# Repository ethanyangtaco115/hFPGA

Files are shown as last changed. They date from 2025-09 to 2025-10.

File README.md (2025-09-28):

# hFPGA (WIP)

A modified PicoEVB FPGA board made for rapid prototyping, DIY projects, and making FPGAs more accessible to hobbyists
Sub-System of our Flash LiDAR Project

## Acknowledgements

 - [Major Credit to PicoEVB creators, who made the base schematic for our design.](https://github.com/RHSResearchLLC/PicoEVB/tree/master)

## Features

- 78 Total I/O Pins
- SPI Flash Boot capability
- Integrated USB-JTAG support
- 4 ADC Pins
- 4 Clock Output Pins
- 4 3.3v PWR Pins
- 6 True Single-Ended GPIO Pins
- 15 Differential Lines, with Pseudo-Single Ended capability
- 24 GND Pins

# Authors

Created by [Ethan Yang](https://github.com/ethanyangtaco115) & [Stanley Wang](https://github.com/GhostWinterOwl)

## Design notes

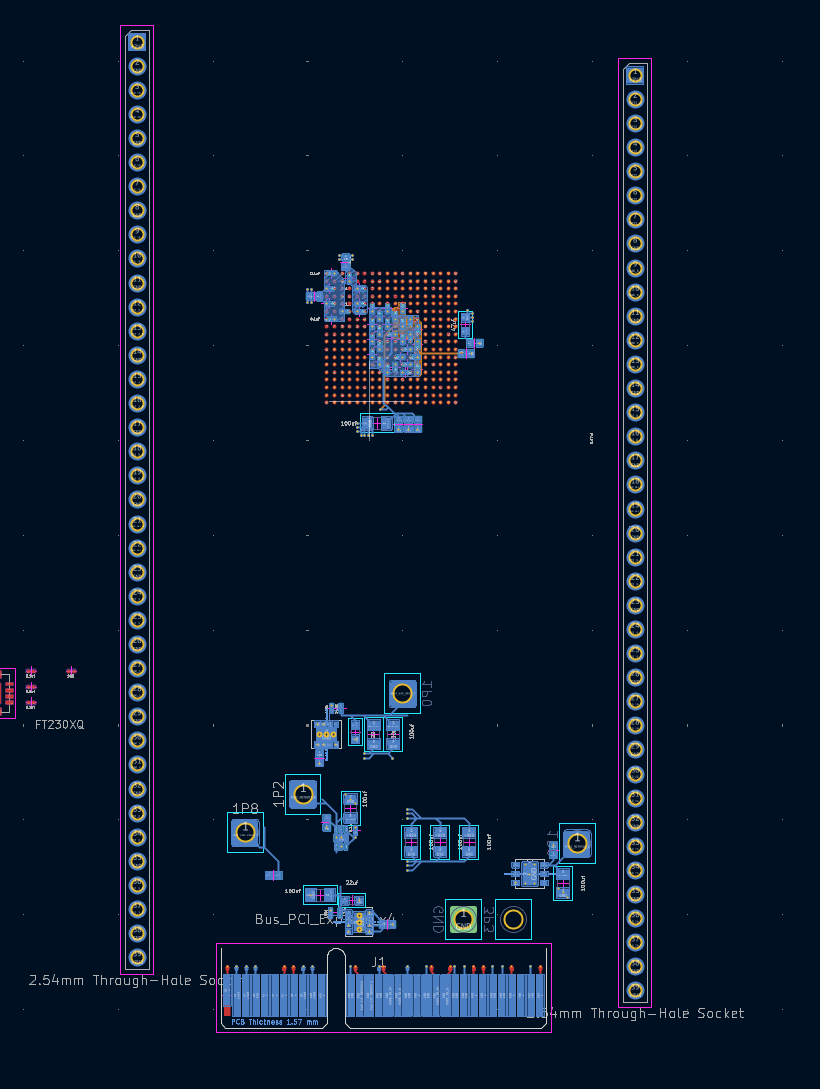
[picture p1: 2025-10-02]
images/image.png

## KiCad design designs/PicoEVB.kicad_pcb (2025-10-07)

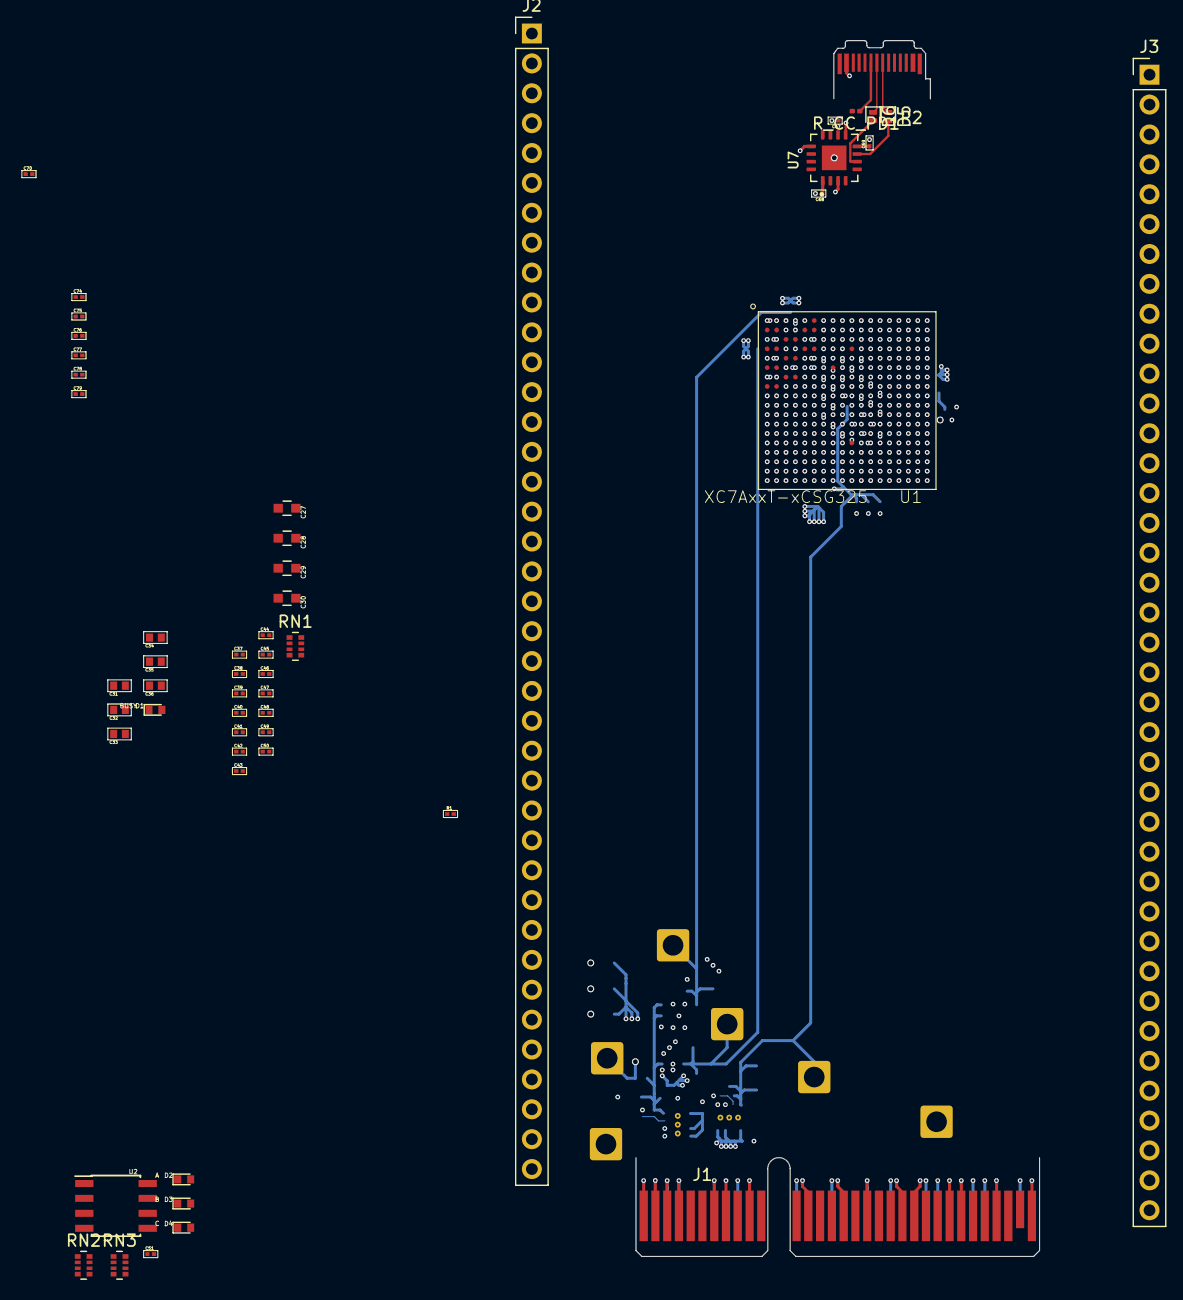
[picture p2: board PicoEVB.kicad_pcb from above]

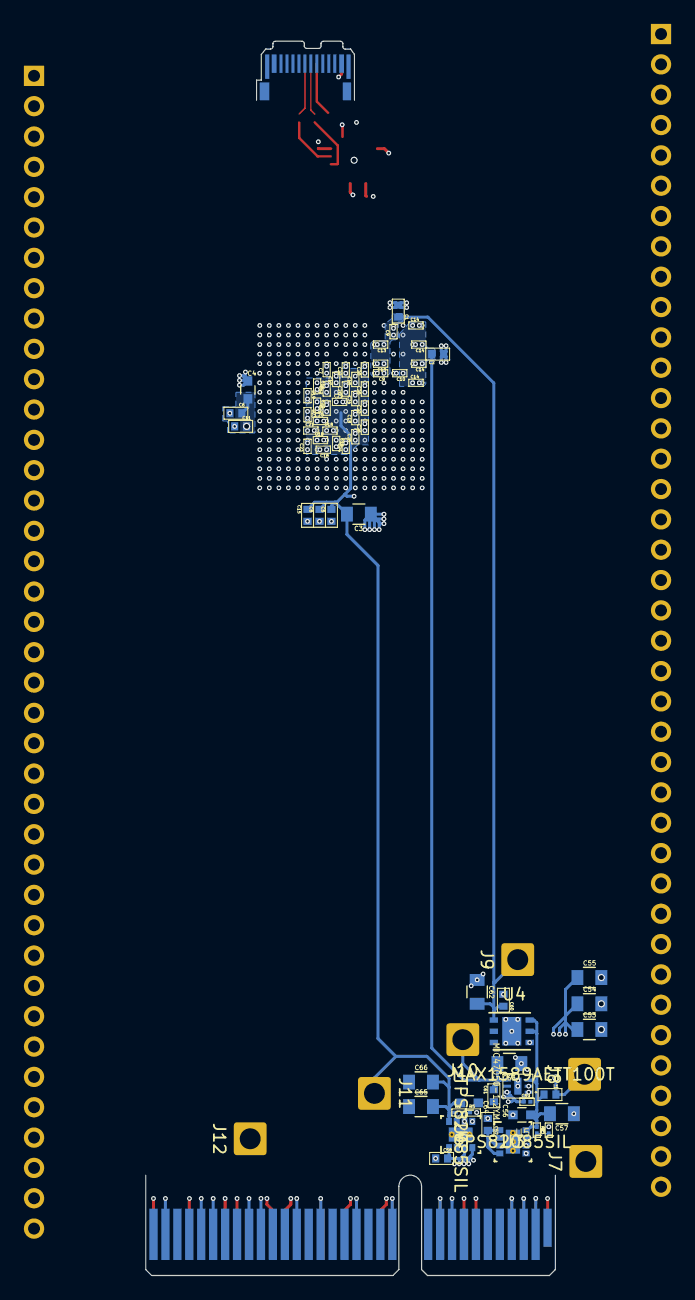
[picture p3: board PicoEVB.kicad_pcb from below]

Board: 6 copper layers, 128 parts (75 on the bottom side), 104 nets.

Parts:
C1, C2, C5, C6, C8, C11, C15, C31, C32, C33, C34, C35, C36: 4.7uf; c_0402
C3, C53, C54, C55, C57, C62, C63, C65, C66: 100uf; C_0805
C4, C27, C28, C29, C30: 47uf; C_0603
C7, C12, C16, C17, C18, C18#2, C18#3, C18#4, C18#5, C18#6, C19, C20, C20#2, C20#3, C21, C21#2, C22, C22#2, C22#3, C23, C23#2, C24, C24#2, C25, C25#2, C26, C26#2, C37, C38, C39, C40, C41, C42, C43, C44, C45, C46, C47, C48, C49, C50, C70: 0.47uf; c_0201_least
C9, C9#2, C10, C13, C13#2, C14, C14#2, C14#3, C14#4, C51, C59, C67, C68, C69, C74, C75, C76, C77, C78, C79: 0.1uf; c_0201_least
C52, C58, C60, C61: 10uf; c_0402
C56, C64: 22uf; C_0603
D1: BUSY; LED_0402
D2: A; LED_0402
D3: B; LED_0402
D4: C; LED_0402
D5, D6: PESD5V0S1UL; D_SOD-882
J1: Bus_PCI_Express_x4; BUS_PCIexpress_x4
J2, J3: 2.54mm Through-Hole Socket; PinHeader_1x39_P2.54mm_Vertical
J7: 3P3; SolderWire-1sqmm_1x01_D1.4mm_OD2.7mm
J8: 1P8; SolderWire-1sqmm_1x01_D1.4mm_OD2.7mm
J9, J11: 1P0; SolderWire-1sqmm_1x01_D1.4mm_OD2.7mm
J10: 1P2; SolderWire-1sqmm_1x01_D1.4mm_OD2.7mm
J12: GND; SolderWire-1sqmm_1x01_D1.4mm_OD2.7mm
L1: 330; r_0402
P2: USB_C_Plug_USB2.0; USB_C_Plug_JAE_DX07P024AJ1
R1: 100; r_0201_least
R2: 124k; r_0201_least
R3, R5: 100k; r_0201_least
R4: 24.9k; r_0201_least
RN1, RN3: 4.7K; R_Array_Convex_4x0402
RN2: 681; R_Array_Convex_4x0402
R_CC_PD1: 5.1k; R_0201_0603Metric
U1: XC7AxxT-xCSG325; CSG-324
U2: S25Q; SOIC-8_3.9x4.9mm_Pitch1.27mm
U3, U6: TPS82085SIL; TPS82084SILR
U4: MAX1589AETT100T
U5: MIC47050-1.2YML; MIC47050-DFN-6-2MM
U7: FT230XQ; QFN65P400X400X80-17N

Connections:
+3V3: C52.1, C53.1, C54.1, C55.1, C58.1, C59.1, C67.1, C68.1, C69.1, C70.2, J1.A2 (+12V), J1.A3 (+12V), J1.A9 (+3.3V), J1.A10 (+3.3V), J1.B1 (+12V), J1.B2 (+12V), J1.B3 (+12V), J1.B8 (+3.3V), J1.B10 (3.3Vaux), J2.1, J2.39, J3.1, J3.39, U3.1 (EN), U3.3 (VIN), U3.4 (VIN), U5.1 (BIAS), U5.6 (EN), U6.1 (EN), U6.3 (VIN), U6.4 (VIN), U7.1 (VCCIO), U7.8 (3V3OUT), U7.10 (VCC)
BUSY_LED_PU: D1.2 (A), RN2.5 (R4.2)
DIO_1_N: J2.36, U1.B17 (IO_L16N_T2_A27_15)
DIO_1_P: J2.37, U1.C16 (IO_L16P_T2_A28_15)
DIO_2_N: J2.33, U1.D18 (IO_L17N_T2_A25_15)
DIO_2_P: J2.34, U1.E17 (IO_L17P_T2_A26_15)
DIO_3_N: J2.24, U1.C18 (IO_L18N_T2_A23_15)
DIO_3_P: J2.25, U1.C17 (IO_L18P_T2_A24_15)
DIO_4_N: J3.16, U1.G16 (IO_L20N_T3_A19_15)
DIO_4_P: J3.15, U1.H16 (IO_L20P_T3_A20_15)
DIO_5_N: J2.18, U1.F14 (IO_L22N_T3_A16_15)
DIO_5_P: J2.19, U1.G14 (IO_L22P_T3_A17_15)
DIO_6_N: J3.22, U1.H18 (IO_L23N_T3_FWE_B_15)
DIO_6_P: J3.21, U1.H17 (IO_L23P_T3_FOE_B_15)
DIO_7_N: J2.15, U1.E18 (IO_L24N_T3_RS0_15)
DIO_7_P: J2.16, U1.F17 (IO_L24P_T3_RS1_15)
DIO_8_N: J3.25, U1.K5 (IO_L1N_T0_34)
DIO_8_P: J3.24, U1.K6 (IO_L1P_T0_34)
DIO_9_N: J2.12, U1.J4 (IO_L2N_T0_34)
DIO_9_P: J2.13, U1.J5 (IO_L2P_T0_34)
DIO_10_N: J3.28, U1.L2 (IO_L4N_T0_34)
DIO_10_P: J3.27, U1.K3 (IO_L4P_T0_34)
DIO_11_N: J2.9, U1.L3 (IO_L5N_T0_34)
DIO_11_P: J2.10, U1.L4 (IO_L5P_T0_34)
DIO_12_N: J3.31, U1.M1 (IO_L7N_T1_34)
DIO_12_P: J3.30, U1.M2 (IO_L7P_T1_34)
DIO_13_N: J2.6, U1.N6 (IO_L8N_T1_34)
DIO_13_P: J2.7, U1.M6 (IO_L8P_T1_34)
DIO_14_N: J3.34, U1.N4 (IO_L10N_T1_34)
DIO_14_P: J3.33, U1.M4 (IO_L10P_T1_34)
DIO_15_N: J2.3, U1.T3 (IO_L17N_T2_34)
DIO_15_P: J2.4, U1.T4 (IO_L17P_T2_34)
DIO_16_N: J3.37, U1.V4 (IO_L18N_T2_34)
DIO_16_P: J3.36, U1.U4 (IO_L18P_T2_34)
FPGA_CCLK_0_B: U1.E8 (CCLK_0), U2.6 (SCK)
GND: C1.2, C2.2, C3.2, C4.2, C5.2, C6.2, C7.2, C8.2, C9.2, C9#2.2, C10.2, C11.2, C12.2, C13.2, C13#2.2, C14.2, C14#2.2, C14#3.2, C14#4.2, C15.2, C16.2, C17.2, C18.2, C18#2.2, C18#3.2, C18#4.2, C18#5.2, C18#6.2, C19.2, C20.2, C20#2.2, C20#3.2, C21.2, C21#2.2, C22.2, C22#2.2, C22#3.2, C23.2, C23#2.2, C24.2, C24#2.2, C25.2, C25#2.2, C26.2, C26#2.2, C27.2, C28.2, C29.2, C30.2, C31.2, C32.2, C33.2, C34.2, C35.2, C36.2, C37.2, C38.2, C39.2, C40.2, C41.2, C42.2, C43.2, C44.2, C45.2, C46.2, C47.2, C48.2, C49.2, C50.2, C51.2, C52.2, C53.2, C54.2, C55.2, C56.2, C57.2, C58.2, C59.2, C60.2, C61.2, C62.2, C63.2, C64.2, C65.2, C66.2, C67.2, C68.2, C69.2, C70.1, J1.A4 (GND), J1.A12 (GND), J1.A15 (GND), J1.A18 (GND), J1.A20 (GND), J1.A23 (GND), J1.A24 (GND), J1.A27 (GND), J1.A28 (GND), J1.A31 (GND), J1.B4 (GND), J1.B7 (GND), J1.B13 (GND), J1.B16 (GND), J1.B18 (GND), J1.B21 (GND), J1.B22 (GND), J1.B25 (GND), J1.B26 (GND), J1.B29 (GND), J1.B32 (GND), J2.2, J2.5, J2.8, J2.11, J2.14, J2.17, J2.20, J2.23, J2.26, J2.29, J2.32, J2.35, J2.38, J3.8, J3.11, J3.14, J3.17, J3.20, J3.23, J3.26, J3.29, J3.32, J3.35, J3.38, J12.1, P2.A1 (GND), P2.A12 (GND), P2.B1 (GND), P2.B12 (GND), P2.S1 (SHIELD), R3.2, R5.2, R_CC_PD1.2, U1.A1 (GND[75]), U1.A3 (MGTPRXN1_216), U1.A4 (MGTPRXP1_216), U1.A5 (GND[75]), U1.A7 (GND[75]), U1.A8 (GND[75]), U1.A11 (GND[75]), U1.A18 (GND[75]), U1.B3 (GND[75]), U1.B7 (GND[75]), U1.B8 (GND[75]), U1.B18 (GND[75]), U1.C2 (GND[75]), U1.C6 (GND[75]), U1.C7 (GND[75]), U1.C15 (GND[75]), U1.D3 (GND[75]), U1.D4 (GND[75]), U1.D7 (GND[75]), U1.D12 (GND[75]), U1.E2 (GND[75]), U1.E6 (GND[75]), U1.E7 (GND[75]), U1.E9 (GND[75]), U1.E11 (VCCBATT_0), U1.F4 (GND[75]), U1.F6 (GND[75]), U1.F10 (GND[75]), U1.F13 (M2_0), U1.F16 (GND[75]), U1.G1 (GND[75]), U1.G5 (GND[75]), U1.G6 (GND[75]), U1.G7 (GND[75]), U1.G9 (GND[75]), U1.G11 (GND[75]), U1.G13 (GND[75]), U1.H3 (GND[75]), U1.H4 (GND[75]), U1.H5 (GND[75]), U1.H6 (GND[75]), U1.H8 (GND[75]), U1.H10 (GND[75]), U1.H12 (GND[75]), U1.J1 (GND[75]), U1.J2 (GND[75]), U1.J3 (GND[75]), U1.J7 (GND[75]), U1.J9 (GNDADC_0), U1.J11 (GND[75]), U1.J13 (GND[75]), U1.J17 (GND[75]), U1.K4 (GND[75]), U1.K8 (GND[75]), U1.K9 (VREFN_0), U1.K10 (VP_0), U1.K12 (GND[75]), U1.K14 (GND[75]), U1.L1 (GND[75]), U1.L7 (GND[75]), U1.L9 (VN_0), U1.L10 (VREFP_0), U1.L11 (GND[75]), U1.L13 (GND[75]), U1.M8 (GND[75]), U1.M9 (DXN_0), U1.M10 (DXP_0), U1.M12 (GND[75]), U1.M18 (GND[75]), U1.N5 (GND[75]), U1.N7 (GND[75]), U1.N9 (GND[75]), U1.N11 (GND[75]), U1.N13 (GND[75]), U1.N15 (GND[75]), U1.P2 (GND[75]), U1.P8 (GND[75]), U1.P12 (GND[75]), U1.R9 (GND[75]), U1.R11 (M1_0), U1.T6 (GND[75]), U1.T16 (GND[75]), U1.U3 (GND[75]), U1.U13 (GND[75]), U1.V1 (GND[75]), U1.V10 (GND[75]), U1.V18 (GND[75]), U2.4 (GND), U3.5 (GND), U3.6 (GND), U3.9 (PAD), U4.4 (GND), U4.7 (GND), U5.2 (GND), U5.7 (GND), U6.5 (GND), U6.6 (GND), U6.9 (PAD), U7.3 (GND), U7.13 (GND), U7.17 (GND)
GPIO_0: J3.2, U1.D10 (IO_0_15)
GPIO_1: J3.3, U1.H14 (IO_25_15)
GPIO_2: J3.4, U1.J6 (IO_0_34)
GPIO_3: J3.5, U1.R6 (IO_25_34)
GPIO_4: J3.6, U1.L14 (IO_0_14)
GPIO_5: J3.7, U1.U10 (IO_25_14)
JTAG_TCK_B: U1.F8 (TCK_0), U7.15 (TXD)
JTAG_TDI_B: U1.T9 (TDI_0), U7.2 (RXD)
JTAG_TDO_B: U1.T8 (TDO_0), U7.16 (~RTS)
JTAG_TMS_B: U1.R8 (TMS_0), U7.4 (~CTS)
MGT0_RX_B+: J1.A16 (PERp0), U1.G4 (MGTPRXP3_216)
MGT0_RX_B-: J1.A17 (PERn0), U1.G3 (MGTPRXN3_216)
MGT0_TX_B+: C76.1, U1.B2 (MGTPTXP3_216)
MGT0_TX_B-: C77.1, U1.B1 (MGTPTXN3_216)
MGT1_RX_B+: J1.A21 (PERp1), U1.E4 (MGTPRXP0_216)
MGT1_RX_B-: J1.A22 (PERn1), U1.E3 (MGTPRXN0_216)
MGT1_TX_B+: C78.1, U1.H2 (MGTPTXP0_216)
MGT1_TX_B-: C79.1, U1.H1 (MGTPTXN0_216)
MGT_REFCLK0_B+: C74.2, U1.B6 (MGTREFCLK1P_216)
MGT_REFCLK0_B-: C75.2, U1.B5 (MGTREFCLK1N_216)
MRCC_Out_0: J3.18, U1.E13 (IO_L12P_T1_MRCC_15)
MRCC_Out_1: J3.19, U1.D14 (IO_L12N_T1_MRCC_15)
MRCC_Out_2: J2.22, U1.E15 (IO_L13P_T2_MRCC_15)
MRCC_Out_3: J2.21, U1.D15 (IO_L13N_T2_MRCC_15)
unnamed: D1.1 (K), RN1.8 (R1.2), U1.F12 (DONE_0)
unnamed: D2.2 (A), RN2.6 (R3.2)
unnamed: D2.1 (K), U1.V14 (IO_L20N_T3_A07_D23_14)
unnamed: D3.2 (A), RN2.8 (R1.2)
unnamed: D3.1 (K), U1.V12 (IO_L21P_T3_DQS_14)
unnamed: D4.2 (A), RN2.7 (R2.2)
unnamed: D4.1 (K), U1.V13 (IO_L21N_T3_DQS_A06_D22_14)
unnamed: D5.1 (K), P2.A7 (D-)
unnamed: D6.1 (K), P2.A6 (D+)
unnamed: C77.2, J1.B15 (PETn0)
unnamed: C79.2, J1.B20 (PETn1)
unnamed: C76.2, J1.B14 (PETp0)
unnamed: C78.2, J1.B19 (PETp1)
unnamed: C74.1, J1.A13 (REFCLK+)
unnamed: C75.1, J1.A14 (REFCLK-)
unnamed: P2.A5 (CC), R_CC_PD1.1
unnamed: RN1.7 (R2.2), U1.T10 (INIT_B_0)
unnamed: RN1.6 (R3.2), U1.P10 (PROGRAM_B_0)
unnamed: RN3.7 (R2.2), U1.J16 (IO_L2N_T0_D03_14), U2.7 (DQ3)
unnamed: RN3.6 (R3.2), U1.J15 (IO_L2P_T0_D02_14), U2.3 (DQ2)
unnamed: RN3.5 (R4.2), U1.L15 (IO_L6P_T0_FCS_B_14), U2.1 (~CS)
unnamed: U1.L17 (IO_L1N_T0_D01_DIN_14), U2.2 (DO/DQ1)
unnamed: U1.K16 (IO_L1P_T0_D00_MOSI_14), U2.5 (DI/DQ0)
unnamed: U1.C3 (MGTPRXN2_216), U1.D1 (MGTPTXN2_216)
unnamed: U1.C4 (MGTPRXP2_216), U1.D2 (MGTPTXP2_216)
unnamed: R1.1, U1.A6 (MGTRREF_216)
unnamed: R2.2, R3.1, U3.7 (FB)
unnamed: C56.1, C57.1, L1.2, R2.1, U3.8 (VOUT), U4.5 (SHDN#), U4.6 (IN), U5.3 (IN)
unnamed: R4.2, R5.1, U6.7 (FB)
P1V0_MGTAVCC_B: C1.1, C9.1, C9#2.1, C13.1, C13#2.1, C60.1, C62.1, J9.1, U1.B4 (MGTAVCC[4]), U1.C5 (MGTAVCC[4]), U1.E5 (MGTAVCC[4]), U1.F5 (MGTAVCC[4]), U4.1 (OUT)
P1V0_VCC_FPGA_B: C3.1, C5.1, C7.1, C8.1, C12.1, C15.1, C17.1, C18.1, C18#2.1, C18#3.1, C18#4.1, C18#5.1, C18#6.1, C20.1, C20#2.1, C20#3.1, C22.1, C22#2.1, C22#3.1, C24.1, C24#2.1, C25.1, C25#2.1, C26.1, C26#2.1, C64.1, C65.1, C66.1, R4.1, U1.F7 (VCCINT[18]), U1.F9 (VCCINT[18]), U1.F11 (VCCBRAM[3]), U1.G8 (VCCINT[18]), U1.G10 (VCCBRAM[3]), U1.H7 (VCCINT[18]), U1.H9 (VCCINT[18]), U1.H11 (VCCBRAM[3]), U1.J8 (VCCINT[18]), U1.J12 (VCCINT[18]), U1.K7 (VCCINT[18]), U1.K11 (VCCINT[18]), U1.L8 (VCCINT[18]), U1.L12 (VCCINT[18]), U1.M7 (VCCINT[18]), U1.M11 (VCCINT[18]), U1.N8 (VCCINT[18]), U1.N10 (VCCINT[18]), U1.N12 (VCCINT[18]), U1.P9 (VCCINT[18]), U1.P11 (VCCINT[18]), U6.8 (VOUT)
P1V2_MGTAVTT_B: C2.1, C10.1, C14.1, C14#2.1, C14#3.1, C14#4.1, C61.1, C63.1, J10.1, R1.2, U1.A2 (MGTAVTT[5]), U1.C1 (MGTAVTT[5]), U1.E1 (MGTAVTT[5]), U1.F3 (MGTAVTT[5]), U1.G2 (MGTAVTT[5]), U5.4 (OUT)
P1V8_FPGA_VCCAUX_B: C4.1, C6.1, C11.1, C16.1, C19.1, C21.1, C21#2.1, C23.1, C23#2.1, J8.1, L1.1, U1.G12 (VCCAUX[5]), U1.H13 (VCCAUX[5]), U1.J10 (VCCADC_0), U1.K13 (VCCAUX[5]), U1.M13 (VCCAUX[5]), U1.P13 (VCCAUX[5])
USB_2+: D6.2 (A), U7.6 (USBDP)
USB_2-: D5.2 (A), U7.7 (USBDM)
VCC_BANK14_B: C27.1, C28.1, C29.1, C30.1, C31.1, C32.1, C33.1, C34.1, C35.1, C36.1, C37.1, C38.1, C39.1, C40.1, C41.1, C42.1, C43.1, C44.1, C45.1, C46.1, C47.1, C48.1, C49.1, C50.1, C51.1, RN1.1 (R1.1), RN1.2 (R2.1), RN1.3 (R3.1), RN1.4 (R4.1), RN2.1 (R1.1), RN2.2 (R2.1), RN2.3 (R3.1), RN2.4 (R4.1), RN3.1 (R1.1), RN3.2 (R2.1), RN3.3 (R3.1), RN3.4 (R4.1), U1.A16 (VCCO_15[7]), U1.B13 (VCCO_15[7]), U1.C10 (VCCO_15[7]), U1.D17 (VCCO_15[7]), U1.E10 (VCCO_0[2]), U1.E12 (CFGBVS_0), U1.E14 (VCCO_15[7]), U1.G18 (VCCO_15[7]), U1.H15 (VCCO_15[7]), U1.J18 (IO_L3P_T0_DQS_PUDC_B_14), U1.L6 (VCCO_34[6]), U1.L16 (VCCO_14[7]), U1.M3 (VCCO_34[6]), U1.P7 (VCCO_34[6]), U1.P17 (VCCO_14[7]), U1.R4 (VCCO_34[6]), U1.R10 (VCCO_0[2]), U1.R12 (M0_0), U1.R14 (VCCO_14[7]), U1.T1 (VCCO_34[6]), U1.T11 (VCCO_14[7]), U1.U8 (VCCO_14[7]), U1.U18 (VCCO_14[7]), U1.V5 (VCCO_34[6]), U1.V15 (VCCO_14[7]), U2.8 (Vcc)
XADC_0_N: J3.10, U1.C8 (IO_L1N_T0_AD0N_15)
XADC_0_P: J3.9, U1.D8 (IO_L1P_T0_AD0P_15)
XADC_1_N: J3.13, U1.C9 (IO_L2N_T0_AD8N_15)
XADC_1_P: J3.12, U1.D9 (IO_L2P_T0_AD8P_15)
XADC_2_N: J2.30, U1.A10 (IO_L5N_T0_AD9N_15)
XADC_2_P: J2.31, U1.B10 (IO_L5P_T0_AD9P_15)
XADC_3_N: J2.27, U1.A12 (IO_L7N_T1_AD2N_15)
XADC_3_P: J2.28, U1.B12 (IO_L7P_T1_AD2P_15)

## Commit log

2025-09-17 add schematic
    [M2_edge_b.kicad_sch, PicoEVB.kicad_sch, USB_IO_b.kicad_sch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]
2025-09-17 Update and rename M2_edge_b.kicad_sch to design/schematics/M2_edge_b.kicad_sch
    [M2_edge_b.kicad_sch]
2025-09-17 Update and rename design/schematics/M2_edge_b.kicad_sch to design/M2_edge_b.kicad_sch
    [M2_edge_b.kicad_sch]
2025-09-17 Create schematic
2025-09-17 add schematics and project file
    [USB_IO_b.kicad_sch, all_external_connections.kicad_sch, fpga_io_b.kicad_sch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]
2025-09-18 finished schematics
    [M2_edge_b.kicad_sch, PicoEVB.kicad_sch, fpga_io_b.kicad_sch]
2025-09-18 Update and rename M2_edge_b.kicad_sch to M2_edge_b.kicad_sch
    [M2_edge_b.kicad_sch]
2025-09-20 Create kicad_lib
2025-09-26 Add files via upload
    Organized one group power page 2
    [M2_edge_b.kicad_sch, PicoEVB.kicad_pcb, PicoEVB.kicad_sch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]
2025-09-28 Update README.md
    In addition, previous commit, 99% done with power circuits.
2025-09-29 Current Progress as of 28/9/25 22:54
2025-10-01 Add changes
    [PicoEVB.kicad_pcb]
2025-10-02 Commit power circuits for chip
    All power circuits for chip are DONE. In progress: Connecting bottom of board power circuits.
    [PicoEVB.kicad_pcb]
2025-10-03 Finished 3V3 filled zone wiring for all ICs
    IO yet to be wired.
    [PicoEVB.kicad_pcb, power_b.kicad_sch]
2025-10-06 Completed Power Circuitry
    [PicoEVB.kicad_pcb]
2025-10-07 progress 10% to USB JTAG
    [PicoEVB.kicad_pcb]

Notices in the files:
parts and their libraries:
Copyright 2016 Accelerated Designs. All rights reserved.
